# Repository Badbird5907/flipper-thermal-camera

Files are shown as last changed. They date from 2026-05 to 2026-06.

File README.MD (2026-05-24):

# Flipper Zero Thermal Camera

This is a thermal camera module for the Flipper Zero!

It uses the MLX90640 thermal sensor, with a *whopping* resolution of 32x24, and a suite of other auxiliary sensors, including:
- VEML7700 Light Sensor
- ICM-20948 IMU
- SHT31 Temperature & Humidity Sensor

All 4 sensors communicate to the flipper via it's I2C bus.

### The PCB
This is a simple two-layer PCB that mounts the MLX90640 and VEML7700 sensors in the front, and the ICM-20948 and SHT31 on the back.
It uses two 90-degree header pins to connect to the flipper zero's GPIO.

render
pcb
schematic

**Why no case?** Most flipper PCB mods don't use a case to show off the PCB. I think it especially goes better with my flipper as it has a clear case mod.

### The App

I have the app bootstrapped in [flipper-app](/flipper-app). It's not complete yet as I cannot test without the PCB.

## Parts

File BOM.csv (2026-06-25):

Index | Quantity | Part Number | Manufacturer Part Number | Description | Customer Reference | Available | Backorder | Unit Price | Extended Price CAD
1 | 10 | 478-KGM21ER71H124KUCT-ND | KGM21ER71H124KU | CAP CER 0.12UF 50V X7R 0805 |  | 10 | 0 | 0.176 | 1.76
2 | 10 | 311-1.50KCRCT-ND | RC0805FR-071K5L | RES 1.5K OHM 1% 1/8W 0805 |  | 10 | 0 | 0.053 | 0.53
3 | 10 | 1276-1003-1-ND | CL21B104KBCNNNC | CAP CER 0.1UF 50V X7R 0805 |  | 10 | 0 | 0.056 | 0.56
4 | 10 | 311-10.0KCRCT-ND | RC0805FR-0710KL | RES 10K OHM 1% 1/8W 0805 |  | 10 | 0 | 0.053 | 0.53
5 | 10 | 490-GRM155R60J106ME05DCT-ND | GRM155R60J106ME05D | CAP CER 10UF 6.3V X5R 0402 |  | 10 | 0 | 0.031 | 0.31
6 | 10 | 1276-1029-1-ND | CL21B105KBFNNNE | CAP CER 1UF 50V X7R 0805 |  | 10 | 0 | 0.094 | 0.94
7 | 10 | 311-2.2KARCT-ND | RC0805JR-072K2L | RES 2.2K OHM 5% 1/8W 0805 |  | 10 | 0 | 0.05 | 0.5
8 | 10 | 1276-1244-1-ND | CL21A475KAQNNNE | CAP CER 4.7UF 25V X5R 0805 |  | 10 | 0 | 0.089 | 0.89
9 | 1 | 828-1058-1-ND | BNO055 | IMU ACCEL/GYRO/MAG I2C 28LGA |  | 1 | 0 | 20 | 20
10 | 10 | 160-1426-1-ND | LTST-C171KGKT | LED GREEN CLEAR SMD |  | 10 | 0 | 0.125 | 1.25
11 | 10 | 160-1415-1-ND | LTST-C170KRKT | LED RED CLEAR SMD |  | 10 | 0 | 0.137 | 1.37
12 | 1 | MLX90640ESF-BAA-000-SP-ND | MLX90640ESF-BAA-000-SP | SENSOR DGTL -40C-85C TO39 |  | 1 | 0 | 59.89 | 59.89
13 | 10 | 5399-RB521S-30CT-ND | RB521S-30 | 30V INDEPENDENT TYPE 500MV@200MA |  | 10 | 0 | 0.072 | 0.72
14 | 1 | 1649-1011-1-ND | SHT31-DIS-B2.5KS | SENSOR HUMID/TEMP 5V I2C 2% SMD |  | 1 | 0 | 7.02 | 7.02
15 | 1 | F2897CT-ND | SP1001-05JTG | TVS DIODE 5.5VWM 13VC SC706 |  | 1 | 0 | 1.61 | 1.61
16 | 1 | 751-VEML7700-TTCT-ND | VEML7700-TT | SENSOR OPT AMBIENT 4 SMD J LEAD |  | 1 | 0 | 2 | 2
17 | 1 | 893-XC6206P332MR-GCT-ND | XC6206P332MR-G | IC REG LINEAR 3.3V 200MA SOT23 |  | 1 | 0 | 0.97 | 0.97
18 | 2 | 2057-PH1RB-20-UA-ND | PH1RB-20-UA | CONN HEADER R/A 20POS 2.54MM |  | 2 | 0 | 0.78 | 1.56
19 | 10 | 541-4168-1-ND | CRCW0805330RJNEAC | RES SMD 330 OHM 5% 1/8W 0805 |  | 10 | 0 | 0.051 | 0.51
 | CAD
SUBTOTAL | $102.92
SHIPPING | FREE
HST | 13.38
TOTAL | $116.30 | CAD
 | $83.39 | USD
PCB + STENCIL | 6.74
SHIPPING | 9.01
TOTAL | 15.75 | USD
GRAND TOTAL | $99.14 | USD

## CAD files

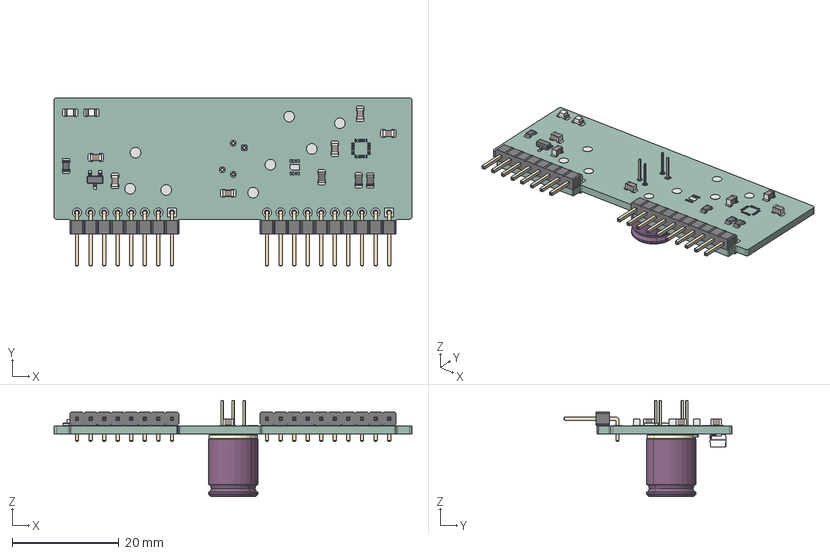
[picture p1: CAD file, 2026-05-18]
model.step
67.0 x 31.5 x 18.1 mm
R_0805_2012Metric x 4
C_0805_2012Metric x 6
PinHeader_1x10_P254mm_Horizontal
LED_0805_2012Metric x 2
PinHeader_1x08_P254mm_Horizontal
SOT-23-3
VEML7700-TR
TO39_ FOV 55
flipper-thermal-camera_pad
flipper-thermal-camera_PCB

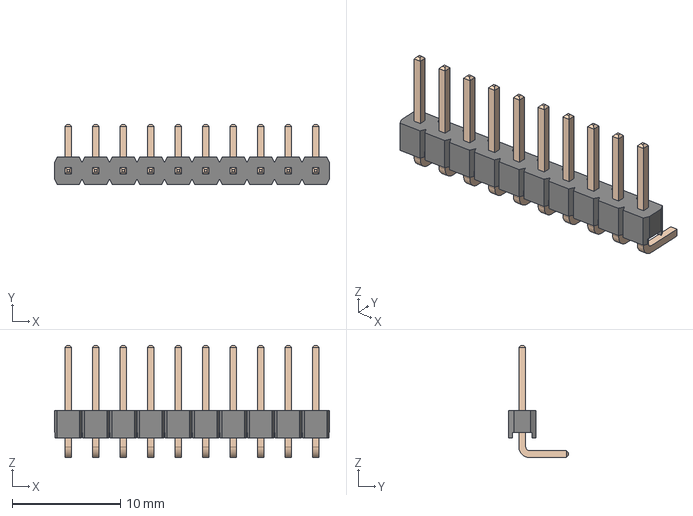
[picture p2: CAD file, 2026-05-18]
PCB/Components/Pin Headers/10.step
25.4 x 5.54 x 10.4 mm
6130xx11021_PIN x 10

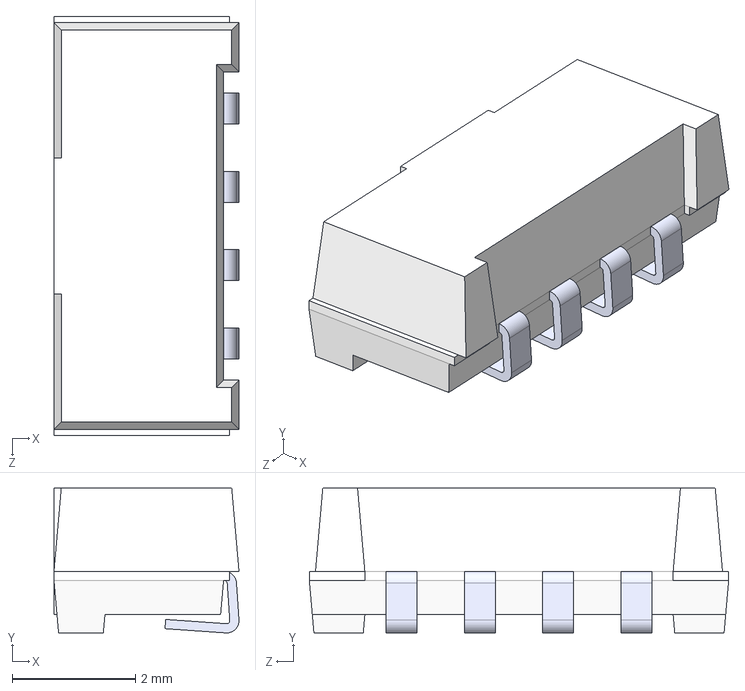
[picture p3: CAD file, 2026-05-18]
PCB/Components/VEML7700-TR.STEP
3.00 x 2.35 x 6.80 mm

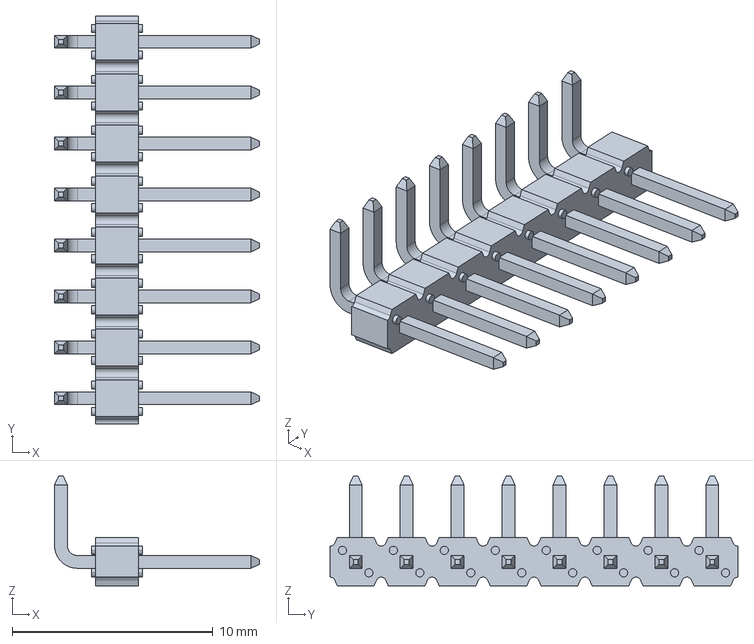
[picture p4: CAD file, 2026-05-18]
PCB/Components/Pin Headers/8.step
10.2 x 20.3 x 5.46 mm

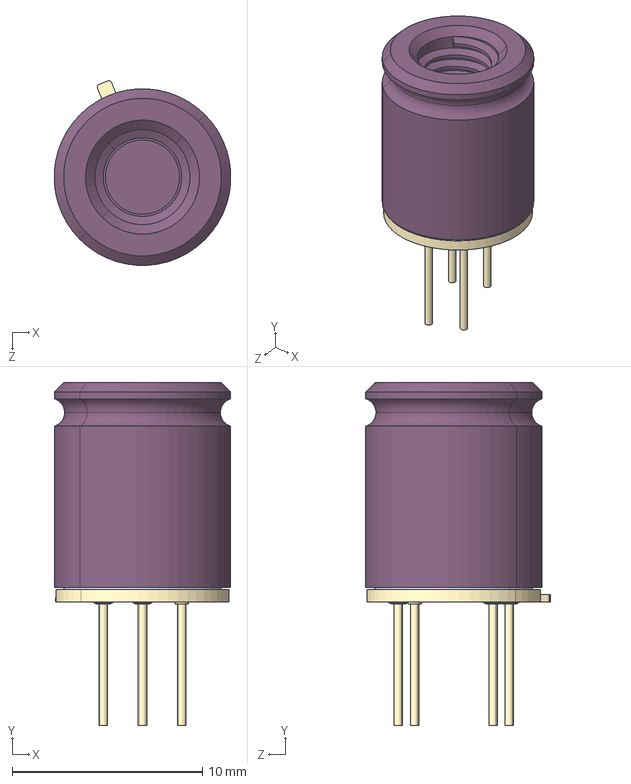
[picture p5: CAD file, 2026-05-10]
PCB/Components/MLX90640ESF-BAB-000-SP.step
9.28 x 18.1 x 9.72 mm

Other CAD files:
PCB/Components/MLX90640.sldprt

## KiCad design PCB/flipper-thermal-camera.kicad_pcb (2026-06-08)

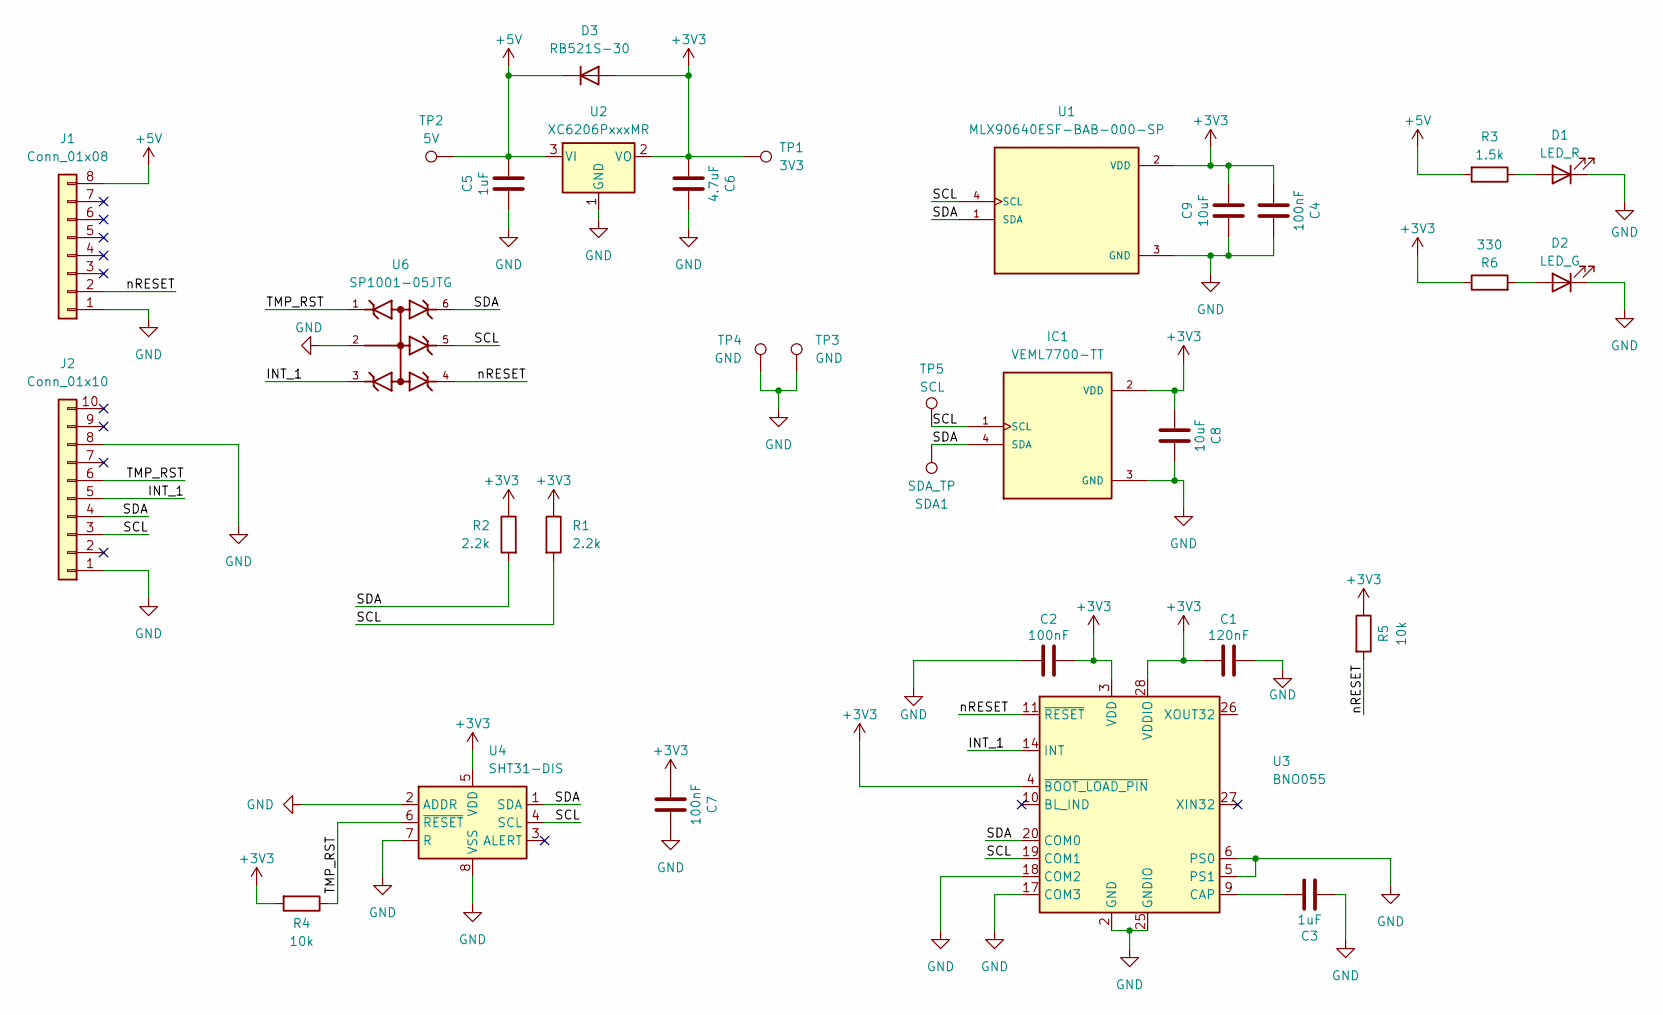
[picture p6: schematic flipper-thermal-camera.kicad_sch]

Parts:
C1: 120nF; C_0805_2012Metric
C2, C4, C7: 100nF; C_0805_2012Metric
C3, C5: 1uF; C_0805_2012Metric
C6: 4.7uF; C_0805_2012Metric
C8, C9: 10uF; C_0805_2012Metric
D1: LED_R; LED_0805_2012Metric
D2: LED_G; LED_0805_2012Metric
D3: RB521S-30; D_SOD-523; LCSC C727120
IC1: VEML7700-TT; XDCR_VEML7700-TT; Manufacturer_Part_Number VEML7700-TT; Mouser Part Number 78-VEML7700-TT
J1: Conn_01x08; PinHeader_1x08_P2.54mm_Horizontal
J2: Conn_01x10; PinHeader_1x10_P2.54mm_Horizontal
R1, R2: 2.2k; R_0805_2012Metric
R3: 1.5k; R_0805_2012Metric
R4, R5: 10k; R_0805_2012Metric
R6: 330; R_0805_2012Metric
SDA1: SDA_TP; TestPoint_Pad_D2.0mm
TP1: 3V3; TestPoint_Pad_D2.0mm
TP2: 5V; TestPoint_Pad_D2.0mm
TP3, TP4: GND; TestPoint_Pad_D2.0mm
TP5: SCL; TestPoint_Pad_D2.0mm
U1: MLX90640ESF-BAB-000-SP; TO292P945H1165-4; PARTREV 11
U2: XC6206PxxxMR; SOT-23-3
U3: BNO055; LGA-28_5.2x3.8mm_P0.5mm
U4: SHT31-DIS; Sensirion_DFN-8-1EP_2.5x2.5mm_P0.5mm_EP1.1x1.7mm
U6: SP1001-05JTG; SOP65P220X110-6N; PARTREV GD

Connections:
+3V3: C1.1, C2.2, C4.1, C6.2, C7.1, C8.1, C9.1, D3.2 (A), IC1.2 (VDD), R1.1, R2.1, R4.2, R5.1, R6.1, TP1.1 (1_1), U1.2 (VDD), U2.2 (VO), U3.3 (VDD), U3.4 (~BOOT_LOAD_PIN), U3.28 (VDDIO), U4.5 (VDD)
+5V: C5.2, D3.1 (K), J1.8, R3.2, TP2.1 (1_1), U2.3 (VI)
/INT_1: J2.5, U3.14 (INT), U6.3
/SCL: IC1.1 (SCL), J2.3, R1.2, TP5.1 (1_1), U1.4 (SCL), U3.19 (COM1), U4.4 (SCL), U6.5
/SDA: IC1.4 (SDA), J2.4, R2.2, SDA1.1 (1_1), U1.1 (SDA), U3.20 (COM0), U4.1 (SDA), U6.6
/TMP_RST: J2.6, R4.1, U4.6 (~RESET), U6.1
/nRESET: J1.2, R5.2, U3.11 (~RESET), U6.4
GND: C1.2, C2.1, C3.1, C4.2, C5.1, C6.1, C7.2, C8.2, C9.2, D1.1 (K), D2.1 (K), IC1.3 (GND), J1.1, J2.1, J2.8, TP3.1 (1_1), TP4.1 (1_1), U1.3 (GND), U2.1 (GND), U3.2 (GND), U3.5 (PS1), U3.6 (PS0), U3.17 (COM3), U3.18 (COM2), U3.25 (GNDIO), U4.2 (ADDR), U4.7 (R), U4.8 (VSS), U4.9 (VSS), U6.2
unnamed: D1.2 (A), R3.1
unnamed: D2.2 (A), R6.2
unnamed: C3.2, U3.9 (CAP)

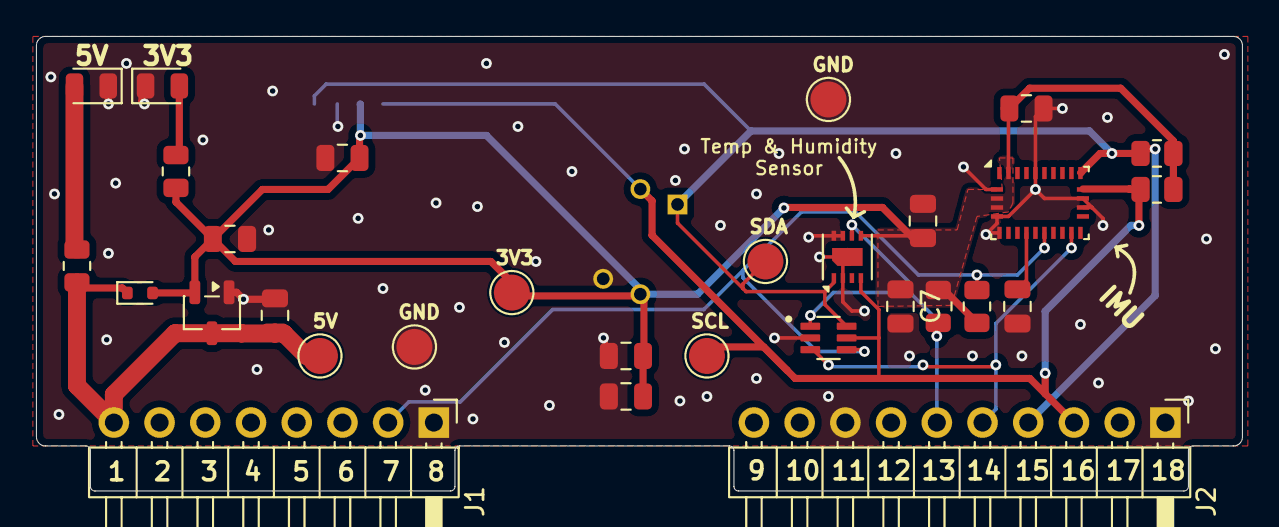
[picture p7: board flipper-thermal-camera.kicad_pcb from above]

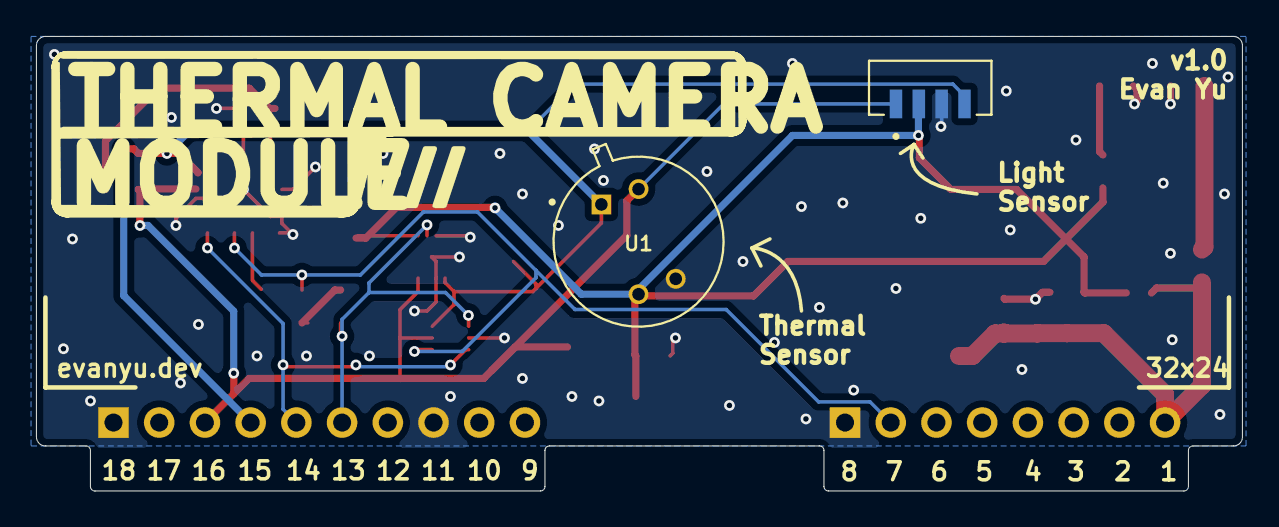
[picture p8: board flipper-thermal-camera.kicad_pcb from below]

Board: 2 copper layers, 67.0 x 25.2 mm, 32 parts (2 on the bottom side), 11 nets.

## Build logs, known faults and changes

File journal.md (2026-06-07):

# 05/09
Initialized this project and started designing the schematic.

I set up just the basic things needed to drive the MLX90640, which is the sensor I decided to go with.
It's really easy to use (over I2C), and has a (low) resolution of 32x24 pixels.

I added a XC6206P332, which is a 3.3v LDO regulator, which steps down the voltage from the 5v Flipper Zero bus to 3.3v.
The reason why we don't use the Flipper's 3.3v line is because the flipper's SD card shares that line, and it's best we avoid using it if possible.

I also added 2.2k pull-up resistors for the I2C lines, and some LEDs to indicate the power status.
Next i'm going to add some other sensors, like a ambient light sensor.

# 05/10

I finished the schematic. I added a light sensor (SHT31), an ambient light sensor (VEML7700), and a IMU (ICM-20948) which alos includes a 3-axis compass.

I'm now working on designing and laying out the PCB.
---
I've finished placing components and routing the PCB. I'll spend the next few days refining the design and adding other things too 



---
Just spent a stupid amount of time fixing the edge.cuts layer and adding rounded corners
rounded corners

---

I finished up the PCB design and added some testpoints. Next, i'll work on sourcing the parts, and then i'll design the case.

pcb render

# 05/18

I sourced all the parts and created a bom (BOM.csv). I also had to spend some time reworking the connector in the schematic, but we're good to go now :)

Next, i'm going to get started on the flipper app

Btw, i've decided against designing a case, as it kind of goes against the flipper's aesthetic (especially mine, which has a clear case mod). Most pcb mods on top have no case to showcase the PCB, so I think it's best if I just don't make one.

# 05/19

Okay, I think this is as far as I can get it until I get the PCB manufactured and built. There's some sample code that probably won't work in [flipper-app](/flipper-app)

# 05/24

Updated the silkscreen with a better/larger stylized "title" inspired by the video game module.
This took over 2-3 hours to do because I had first designed it in affinity designer.
After fiddling around with vectors, I finally got something that looks half-decent. Importing the vector into KiCad was the hardest part.
Importing it directly into KiCad made the black background take over the white text (kind of a skill issue on my part). The closest I got 
was to convert the SVG into a DXF and importing that. It gave me a outline but no background.
I then spent the next hour fiddling around with the DXF in autodesk trying to fill in the text, but nothing really looked good (DXF conversion
dropped the curve resolution too much).

I finally gave up and imported a SVG of the border only into KiCad, then used the Text tool to add the text (Knockout on), and then used the
polygon tool to fill in the border. Not the best solution, but it's the best I could come up with.

affinity

KiCad
Render

# 06/07

Had to switch out the existing IMU for a BNO055 as it went out of stock. Using the BNO055 is a upgrade anyway, it can provide both raw and fused 9-axis sensor data over I2C as it has its own ARM processor.

Also added more capacitors for filtering and a diode to prevent frying the LDO by accident with a short, and a diode array to protect the data pins from ESD.

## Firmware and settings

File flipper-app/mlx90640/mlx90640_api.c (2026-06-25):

/**
 * @copyright (C) 2017 Melexis N.V.
 *
 * Licensed under the Apache License, Version 2.0 (the "License");
 * you may not use this file except in compliance with the License.
 * You may obtain a copy of the License at
 *
 *     http://www.apache.org/licenses/LICENSE-2.0
 *
 * Unless required by applicable law or agreed to in writing, software
 * distributed under the License is distributed on an "AS IS" BASIS,
 * WITHOUT WARRANTIES OR CONDITIONS OF ANY KIND, either express or implied.
 * See the License for the specific language governing permissions and
 * limitations under the License.
 *
 */
#include "mlx90640_i2c.h"
#include "mlx90640_api.h"
#include <furi.h>
#include <math.h>

static void ExtractVDDParameters(uint16_t *eeData, paramsMLX90640 *mlx90640);
static void ExtractPTATParameters(uint16_t *eeData, paramsMLX90640 *mlx90640);
static void ExtractGainParameters(uint16_t *eeData, paramsMLX90640 *mlx90640);
static void ExtractTgcParameters(uint16_t *eeData, paramsMLX90640 *mlx90640);
static void ExtractResolutionParameters(uint16_t *eeData, paramsMLX90640 *mlx90640);
static void ExtractKsTaParameters(uint16_t *eeData, paramsMLX90640 *mlx90640);
static void ExtractKsToParameters(uint16_t *eeData, paramsMLX90640 *mlx90640);
static void ExtractAlphaParameters(uint16_t *eeData, paramsMLX90640 *mlx90640);
static void ExtractOffsetParameters(uint16_t *eeData, paramsMLX90640 *mlx90640);
static void ExtractKtaPixelParameters(uint16_t *eeData, paramsMLX90640 *mlx90640);
static void ExtractKvPixelParameters(uint16_t *eeData, paramsMLX90640 *mlx90640);
static void ExtractCPParameters(uint16_t *eeData, paramsMLX90640 *mlx90640);
static void ExtractCILCParameters(uint16_t *eeData, paramsMLX90640 *mlx90640);
static int ExtractDeviatingPixels(uint16_t *eeData, paramsMLX90640 *mlx90640);
static int CheckAdjacentPixels(uint16_t pix1, uint16_t pix2);  
static float GetMedian(float *values, int n);
static int IsPixelBad(uint16_t pixel,paramsMLX90640 *params);
static int ValidateFrameData(uint16_t *frameData);
static int ValidateAuxData(uint16_t *auxData);

static float alphaTemp[MLX90640_PIXEL_NUM];
static float ktaTemp[MLX90640_PIXEL_NUM];
static float kvTemp[MLX90640_PIXEL_NUM];
  
int MLX90640_DumpEE(uint8_t slaveAddr, uint16_t *eeData)
{
     return MLX90640_I2CRead(slaveAddr, MLX90640_EEPROM_START_ADDRESS, MLX90640_EEPROM_DUMP_NUM, eeData);
}

int MLX90640_SynchFrame(uint8_t slaveAddr)
{
    uint16_t dataReady = 0;
    uint16_t statusRegister;
    int error = 1;
    
    error = MLX90640_I2CWrite(slaveAddr, MLX90640_STATUS_REG, MLX90640_INIT_STATUS_VALUE);
    if(error == -MLX90640_I2C_NACK_ERROR)
    {
        return error;
    }
    
    while(dataReady == 0)
    {
        error = MLX90640_I2CRead(slaveAddr, MLX90640_STATUS_REG, 1, &statusRegister);
        if(error != MLX90640_NO_ERROR)
        {
            return error;
        }    
        //dataReady = statusRegister & 0x0008;
        dataReady = MLX90640_GET_DATA_READY(statusRegister); 
    }     
    
   return MLX90640_NO_ERROR;   
}

int MLX90640_TriggerMeasurement(uint8_t slaveAddr)
{
    int error = 1;
    uint16_t ctrlReg;
    
    error = MLX90640_I2CRead(slaveAddr, MLX90640_CTRL_REG, 1, &ctrlReg);
    
    if ( error != MLX90640_NO_ERROR) 
    {
        return error;
    }    
                                                
    ctrlReg |= MLX90640_CTRL_TRIG_READY_MASK;
    error = MLX90640_I2CWrite(slaveAddr, MLX90640_CTRL_REG, ctrlReg);
    
    if ( error != MLX90640_NO_ERROR)
    {
        return error;
    }    
    
    error = MLX90640_I2CGeneralReset();
    
    if ( error != MLX90640_NO_ERROR)
    {
        return error;
    }    
    
    error = MLX90640_I2CRead(slaveAddr, MLX90640_CTRL_REG, 1, &ctrlReg);
    
    if ( error != MLX90640_NO_ERROR)
    {
        return error;
    }    
    
    if ((ctrlReg & MLX90640_CTRL_TRIG_READY_MASK) != 0)
    {
        return -MLX90640_MEAS_TRIGGER_ERROR;
    }
    
    return MLX90640_NO_ERROR;    
}
    
int MLX90640_GetFrameData(uint8_t slaveAddr, uint16_t *frameData)
{
    uint16_t dataReady = 0;
    uint16_t controlRegister1;
    uint16_t statusRegister;
    int error = 1;
    uint16_t data[64];
    uint8_t cnt = 0;
    
    while(dataReady == 0)
    {
        error = MLX90640_I2CRead(slaveAddr, MLX90640_STATUS_REG, 1, &statusRegister);
        if(error != MLX90640_NO_ERROR)
        {
            return error;
        }    
        //dataReady = statusRegister & 0x0008;
        dataReady = MLX90640_GET_DATA_READY(statusRegister); 
    }      
    
    error = MLX90640_I2CWrite(slaveAddr, MLX90640_STATUS_REG, MLX90640_INIT_STATUS_VALUE);
    if(error == -MLX90640_I2C_NACK_ERROR)
    {
        return error;
    }
                     
    error = MLX90640_I2CRead(slaveAddr, MLX90640_PIXEL_DATA_START_ADDRESS, MLX90640_PIXEL_NUM, frameData); 
    if(error != MLX90640_NO_ERROR)
    {
        return error;
    }                       
    
    error = MLX90640_I2CRead(slaveAddr, MLX90640_AUX_DATA_START_ADDRESS, MLX90640_AUX_NUM, data); 
    if(error != MLX90640_NO_ERROR)
    {
        return error;
    }     
        
    error = MLX90640_I2CRead(slaveAddr, MLX90640_CTRL_REG, 1, &controlRegister1);
    frameData[832] = controlRegister1;
    //frameData[833] = statusRegister & 0x0001;
    frameData[833] = MLX90640_GET_FRAME(statusRegister);
    
    if(error != MLX90640_NO_ERROR)
    {
        return error;
    }
    
    error = ValidateAuxData(data);
    if(error == MLX90640_NO_ERROR)
    {
        for(cnt=0; cnt<MLX90640_AUX_NUM; cnt++)
        {
            frameData[cnt+MLX90640_PIXEL_NUM] = data[cnt];
        }
    }        
    
    error = ValidateFrameData(frameData);
    if (error != MLX90640_NO_ERROR)
    {
        return error;
    }
    
    return frameData[833];    
}

static int ValidateFrameData(uint16_t *frameData)
{
    uint8_t line = 0;
    
    for(int i=0; i<MLX90640_PIXEL_NUM; i+=MLX90640_LINE_SIZE)
    {
        if((frameData[i] == 0x7FFF) && (line%2 == frameData[833])) return -MLX90640_FRAME_DATA_ERROR;
        line = line + 1;
    }    
        
    return MLX90640_NO_ERROR;    
}

static int ValidateAuxData(uint16_t *auxData)
{
    
    if(auxData[0] == 0x7FFF) return -MLX90640_FRAME_DATA_ERROR;    
    
    for(int i=8; i<19; i++)
    {
        if(auxData[i] == 0x7FFF) return -MLX90640_FRAME_DATA_ERROR;
    }
    
    for(int i=20; i<23; i++)
    {
        if(auxData[i] == 0x7FFF) return -MLX90640_FRAME_DATA_ERROR;
    }
    
    for(int i=24; i<33; i++)
    {
        if(auxData[i] == 0x7FFF) return -MLX90640_FRAME_DATA_ERROR;
    }
    
    for(int i=40; i<51; i++)
    {
        if(auxData[i] == 0x7FFF) return -MLX90640_FRAME_DATA_ERROR;
    }
    
    for(int i=52; i<55; i++)
    {
        if(auxData[i] == 0x7FFF) return -MLX90640_FRAME_DATA_ERROR;
    }
    
    for(int i=56; i<64; i++)
    {
        if(auxData[i] == 0x7FFF) return -MLX90640_FRAME_DATA_ERROR;
    }
    
    return MLX90640_NO_ERROR;
    
}
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

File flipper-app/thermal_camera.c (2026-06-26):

#include <furi.h>
#include <furi_hal.h>
#include <gui/gui.h>
#include <gui/view.h>
#include <gui/view_dispatcher.h>
#include <input/input.h>
#include <notification/notification_messages.h>
#include <power/power_service/power.h>
#include <stdlib.h>
#include <string.h>

#include "mlx90640/mlx90640_i2c.h"
#include "ui/display.h"

#define TAG "ThermalCamera"

#define THERMAL_CAMERA_VIEW_MAIN       0U
#define THERMAL_CAMERA_REFRESH_4HZ_REG 0x03U
#define THERMAL_CAMERA_REFRESH_8HZ_REG  0x04U
#define THERMAL_CAMERA_REFRESH_16HZ_REG 0x05U
#define THERMAL_CAMERA_OVERLAY_MS      2000U
#define THERMAL_CAMERA_UI_TICK_MS      125U
#define THERMAL_CAMERA_SENSOR_STACK    (6U * 1024U)
#define THERMAL_CAMERA_5V_WAIT_MS      100U
#define THERMAL_CAMERA_5V_WAIT_RETRIES 10U

typedef struct {
    Gui* gui;
    NotificationApp* notification;
    Power* power;
    ViewDispatcher* view_dispatcher;
    View* view;
    FuriThread* sensor_thread;
    FuriMutex* frame_mutex;

    float frame[THERMAL_FRAME_PIXELS];
    float sensor_frame[THERMAL_FRAME_PIXELS];
    ThermalCameraRenderData render_data;
    uint16_t eeprom[MLX90640_EEPROM_DUMP_NUM];
    paramsMLX90640 sensor_params;
    bool has_frame;
    bool sensor_present;
    bool frozen;
    volatile bool stop_requested;
    ThermalCameraMode mode;
    float emissivity;
    uint8_t refresh_rate_hz;
    uint8_t refresh_rate_reg;
    float fps;
    uint32_t last_frame_tick;
    uint32_t overlay_until_tick;
} ThermalCameraApp;

static uint32_t thermal_camera_tick_to_ms(uint32_t tick) {
    return (tick * 1000U) / furi_kernel_get_tick_frequency();
}

static uint8_t thermal_camera_hz_to_reg(uint8_t hz) {
    if(hz >= 16U) {
        return THERMAL_CAMERA_REFRESH_16HZ_REG;
    }

    return (hz >= 8U) ? THERMAL_CAMERA_REFRESH_8HZ_REG : THERMAL_CAMERA_REFRESH_4HZ_REG;
}

static uint8_t thermal_camera_reg_to_hz(uint8_t reg) {
    if(reg >= THERMAL_CAMERA_REFRESH_16HZ_REG) {
        return 16U;
    }

    return (reg >= THERMAL_CAMERA_REFRESH_8HZ_REG) ? 8U : 4U;
}

static uint8_t thermal_camera_effective_refresh_reg(const ThermalCameraApp* app) {
    return (app->mode == ThermalCameraModeLive) ? THERMAL_CAMERA_REFRESH_16HZ_REG :
                                                   app->refresh_rate_reg;
}

static void thermal_camera_request_redraw(ThermalCameraApp* app) {
    ThermalCameraApp** model = view_get_model(app->view);
    UNUSED(model);
    view_commit_model(app->view, true);
}

static bool thermal_camera_enable_5v(ThermalCameraApp* app) {
    furi_hal_power_suppress_charge_enter();
    power_enable_otg(app->power, true);

    for(uint8_t attempt = 0; attempt < THERMAL_CAMERA_5V_WAIT_RETRIES; attempt++) {
        furi_hal_power_check_otg_status();

        const bool requested = power_is_otg_enabled(app->power);
        const bool enabled = furi_hal_power_is_otg_enabled();
        const bool fault = furi_hal_power_check_otg_fault();

        if(enabled && !fault) {
            FURI_LOG_I(TAG, "5V rail enabled");
            return true;
        }

        FURI_LOG_W(
            TAG,
            "Waiting for 5V rail: requested=%u enabled=%u fault=%u",
            requested,
            enabled,
            fault);
        furi_delay_ms(THERMAL_CAMERA_5V_WAIT_MS);
    }

    FURI_LOG_E(
        TAG,
        "5V rail did not enable: requested=%u enabled=%u fault=%u",
        power_is_otg_enabled(app->power),
        furi_hal_power_is_otg_enabled(),
        furi_hal_power_check_otg_fault());
    return false;
}

static void thermal_camera_disable_5v(ThermalCameraApp* app) {
    if(app->power) {
        power_enable_otg(app->power, false);
    } else {
        furi_hal_power_disable_otg();
    }
    furi_hal_power_suppress_charge_exit();
}

static void thermal_camera_set_sensor_present(ThermalCameraApp* app, bool present) {
    furi_check(furi_mutex_acquire(app->frame_mutex, FuriWaitForever) == FuriStatusOk);
    app->sensor_present = present;
    if(!present) {
        app->has_frame = false;
        app->fps = 0.0f;
    }
    furi_check(furi_mutex_release(app->frame_mutex) == FuriStatusOk);
}

static bool thermal_camera_init_sensor(ThermalCameraApp* app) {
    furi_hal_i2c_acquire(&furi_hal_i2c_handle_external);
    const bool ready = furi_hal_i2c_is_device_ready(
        &furi_hal_i2c_handle_external, (uint8_t)(MLX90640_I2C_ADDRESS << 1), 100);
    furi_hal_i2c_release(&furi_hal_i2c_handle_external);

    if(!ready) {
        FURI_LOG_E(TAG, "MLX90640 probe failed at 0x%02X", MLX90640_I2C_ADDRESS);
        thermal_camera_set_sensor_present(app, false);
        return false;
    }

    if(!mlx90640_read_eeprom(app->eeprom)) {
        FURI_LOG_E(TAG, "MLX90640 EEPROM read failed");
        thermal_camera_set_sensor_present(app, false);
        return false;
    }

    if(!mlx90640_extract_params(app->eeprom, &app->sensor_params)) {
        FURI_LOG_E(TAG, "MLX90640 parameter extraction failed");
        thermal_camera_set_sensor_present(app, false);
        return false;
    }

    furi_check(furi_mutex_acquire(app->frame_mutex, FuriWaitForever) == FuriStatusOk);
    const uint8_t refresh = thermal_camera_effective_refresh_reg(app);
    const float emissivity = app->emissivity;
    furi_check(furi_mutex_release(app->frame_mutex) == FuriStatusOk);

    mlx90640_set_emissivity(emissivity);
    if(!mlx90640_configure(refresh)) {
        FURI_LOG_E(TAG, "MLX90640 configure failed");
        thermal_camera_set_sensor_present(app, false);
        return false;
    }

    thermal_camera_set_sensor_present(app, true);
    return true;
}
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

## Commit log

2026-05-10 add IMU, temp sensor, and light sensor + capacitors
    [flipper-thermal-camera.kicad_sch]
2026-05-10 finish schematic
    [flipper-thermal-camera.kicad_pcb, flipper-thermal-camera.kicad_sch]
2026-05-10 finish routing pcb
    [flipper-thermal-camera.kicad_pcb, flipper-thermal-camera.kicad_sch]
2026-05-10 add testpoints
    [flipper-thermal-camera.kicad_pcb, flipper-thermal-camera.kicad_sch]
2026-05-10 source parts
    [flipper-thermal-camera.kicad_pcb]
2026-05-18 add bom
    [10.step, 8.step, BOM.csv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]
2026-05-19 add readme
    [model.step]
2026-05-19 Enhance README with sensor and PCB information
    Added details about the thermal camera's sensors and PCB design.
2026-05-19 some temp testing code that probably won't work
    [mlx90640_api.c, mlx90640_api.h, mlx90640_i2c.c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]
2026-05-19 Add schematic image to README
    Added schematic image to README.
2026-05-24 update silkscreen & stuff
2026-05-24 add arrows and stuff
    [flipper-thermal-camera.kicad_pcb]
2026-05-24 fix arrow widths
    [flipper-thermal-camera.kicad_pcb]
2026-06-07 switch IMU and add more capacitors and diodes
    [flipper-thermal-camera.kicad_pcb, flipper-thermal-camera.kicad_sch]
2026-06-07 fix up wiring
    [flipper-thermal-camera.kicad_pcb, flipper-thermal-camera.kicad_sch]
2026-06-08 source from digikey
    [BOM.csv, flipper-thermal-camera.kicad_pcb]
2026-06-25 get code working
    [BOM.csv]
